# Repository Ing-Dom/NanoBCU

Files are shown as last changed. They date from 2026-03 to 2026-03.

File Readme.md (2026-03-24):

## Beschreibung

Die NanoBCU ist eine sehr kleine BCU (Bus Coupling Unit) für den KNX-TP1 Gebäudeautomatisierungsbus.  
Sie basiert auf den OnSemi NCN51xx KNX-Tranceiver-ICs. Die Größe der NanoBCU V2 beträgt lediglich 18x17x8 mm.

Mit der BCU können per UART Telegramme auf KNX-TP1 gesendet und empfangen werden. Weiterhin stellt sie die Spannungsversorgung der Geräts über den KNX-TP1 sicher.

Die Informationen hier gelten für die NanBCU V2, für die älteren V0 und V1 Versionen siehe [NanoBCU-V1](https://github.com/OpenKNX/OpenKNX/wiki/NanoBCU-V1)

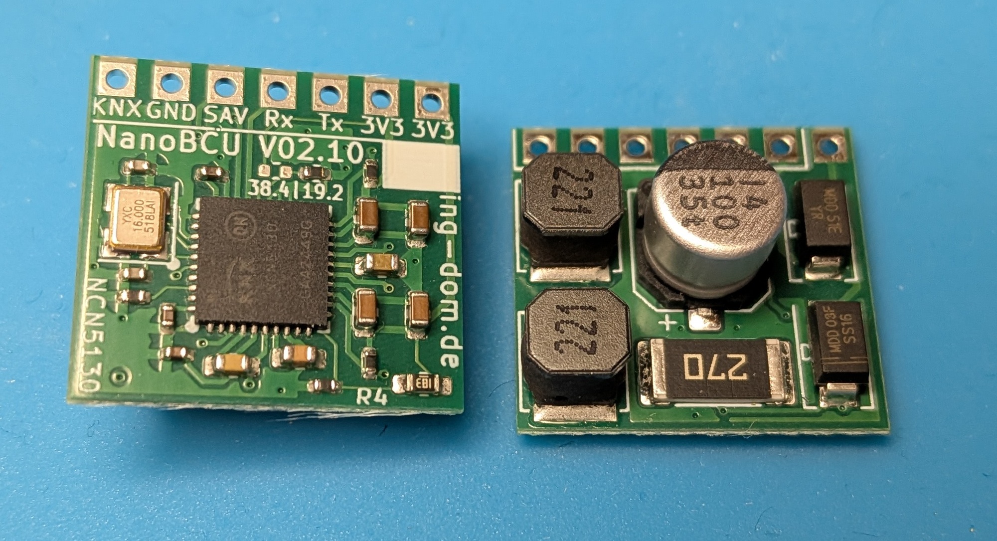
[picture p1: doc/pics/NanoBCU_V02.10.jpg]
NanoBCU V02.00 Top


## Eigenschaften

- IC: NCN5130 (auch NCN5121 und NCN5120)
- Größe: 18 x 17 x 8 mm
- Gewicht: ca. 4g
- Spannung 1: 3.3V
- Spannung 2: 3.3V, 5V, 12V, 21V. Lann durch Tausch der Widerstands R4 geändert werden beliebig geändert werden: 1.2V - 21V
- Ripple: ca. 50-100mV (Abhängig von Spannung und Strom)
- Max. Strom: 100mA @ 3.3V + 100mA @ 5V (2x 100mA nur mit NCN5130)
- Max. Busstrom: 40mA/20mA (5130/ 512x)
- UART: 19200bps 8E1 / Pegel **3.3V**, ab V02.10 wahlweise 38400bps wählbar

## Verfügbarkeit

Der Schaltplan der NanoBCU ist unter der freien [CC-BY-NC-SA](https://creativecommons.org/licenses/by-nc-sa/4.0/legalcode.de) verfügbar.

SMD-bestückte Bausätze können [hier](https://muster.ing-dom.de) gekauft werden.

Die KiCAD-Daten sind und werden nicht veröffentlicht.

## Aufbau

Eine gerade oder gewinkelte 1x7 Stift- oder Buchsenleiste RM 2.54mm einlöten.

## Dokumentation

- [Schematic V02.10](doc/NanoBCU_V02.10.sch.pdf)
- [3D-Modell V02.10](doc/NanoBCU_V02.10.step)

## Software-Integration

Es existieren diverse Bibliotheken mit denen eine NanoBCU genutzt werden kann.

Für ESP32 oder ARM-Mikrocontroller empfehlen wir den [OpenKNX stack](https://github.com/OpenKNX/knx).

Aber auch für kleinere 8Bit Controller als auch für .Net und Java existieren fertige Lösungen.

Das UART-Protokol der NCN51xx ist weitgehend kompatibel zum TPUart daher kann eine NanoBCU in gewissen Grenzen als Ersatz für eine TPUart-basierende Lösung verwendet werden.

## Hardware-Integration

Die [OpenKNX-KiCad-Lib](https://github.com/OpenKNX/OpenKNX-KiCad-Lib) enthält Footprints für diverse Montagemöglickeiten der NanoBCU.

## Benutzung des SAVE Ausgangs

Details zum Verhalten des SAVE-Pins und das Verhalten des NCN bei Busspannungsausfall stehen im jeweiligen NCN51xx-Datenblatt.

Der SAVE pin wird dazu verwendet um einen Busspannungsausfall einige Millisekunden vor dem Zusammenbrechen der 3.3V Versorgung zu erkennenen - der Kondensator der BCU puffert genug Energie um ggf. Daten zu persistieren.

Typischerweise beträgt die Zeit zwischen 50 und 200ms, abhängig vom Strombedarf des Gerätes.

Hier sieht man eine Messung mit einem Gerät mit 8.5ma Stromaufnahme aus dem Bus (ca 35mA @3.3V).
Wie man sehen kann, bleiben ca. 150ms bis die 3.3V Spannung einbricht.
Achtung, der SAVE pin kann prellen!

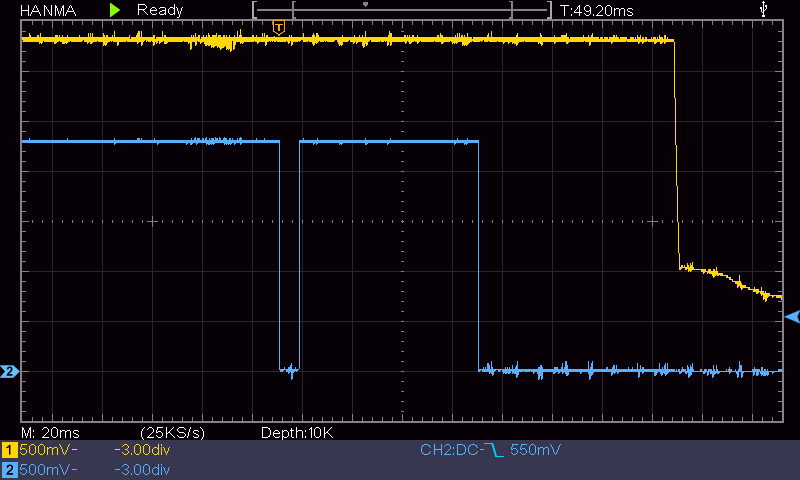
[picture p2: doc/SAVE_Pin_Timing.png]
SAVE Pin Timing


gelb: 3.3V Ausgang der BCU, blau: SAVE pin

## Versionsgeschichte

- V00.10 - erste Prototypenserie
- V00.11 - neuer C4 Kondensator Footprint für die optionale Benutzung eines flachen Tantalkondensators, PCB-Dicke auf 1.0mm reduziert
- V01.00 - OpenKNX-Logo
- V01.10 - Optimierung auf doppelseitige SMD-Maschinenbestückung (C4 nur Alu Cap)
- V02.00 - Verkleinerung auf 17x18, quadratische Lötpads, NCN5130 als Standard-NCN, PCB-Dicke auf 0.8mm reduziert
- V02.10 - Baudrate 19.2/38.4k einstellbar

## Varianten

Details zu den möglichen Bestückvarianten sind im Schaltplan zu finden.

## Links

- [Vorstellungs- / Entwicklunsthread im KNX User Forum](https://knx-user-forum.de/forum/projektforen/konnekting/1603350-nanobcu-ncn5120-weiterentwicklung-der-microbcu2)
- [Sammelbestellung KNX User Forum](https://knx-user-forum.de/forum/projektforen/openknx/1748827-sammelbestellung-nanobcu-und-zubeh%C3%B6r)

## Bilder

NanoBCU V02.00 Top

NanoBCU V02.00 Top

NanoBCU V02.00 Bottom

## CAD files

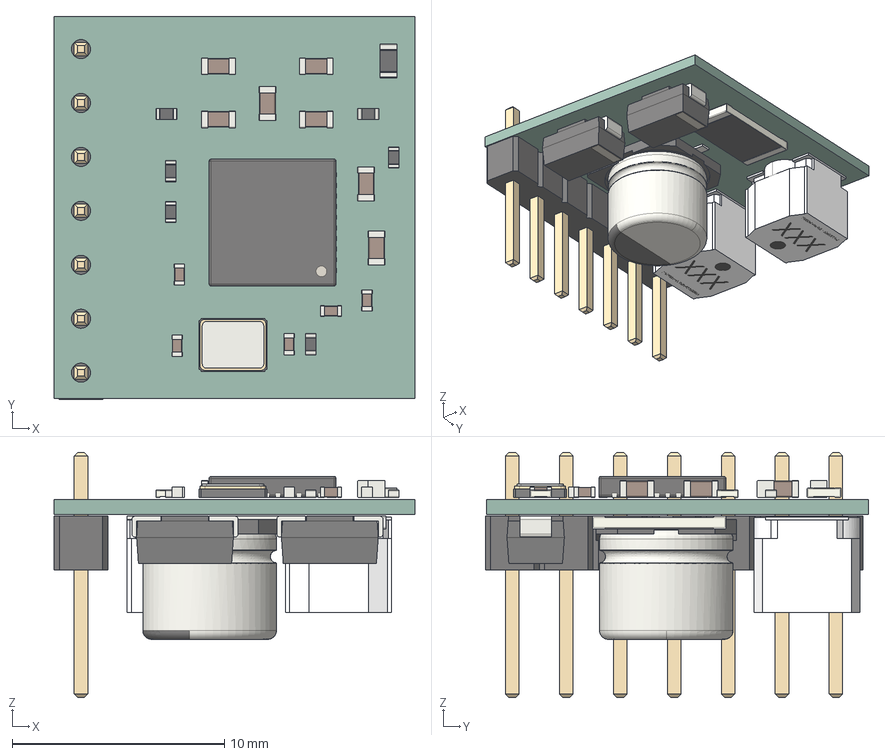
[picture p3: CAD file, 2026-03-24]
doc/NanoBCU_V02.10.step
17.0 x 18.0 x 11.5 mm
C_0603_1608Metric x 7
C_0402_1005Metric x 5
Crystal_SMD_3225-4Pin_3.2x2.5mm
R_0402_1005Metric x 6
QFN-40-1EP_6x6mm_P0.5mm_EP4.6x4.6mm
R_0603_1608Metric
CP_Elec_6.3x5.8
PinHeader_1x07_P2.54mm_Vertical
D_SMA x 2
VLS5045EX_C(3Dmodel) x 2
VLS5045EX_T(3Dmodel) x 2
R_2512_6332Metric
NanoBCU_PCB

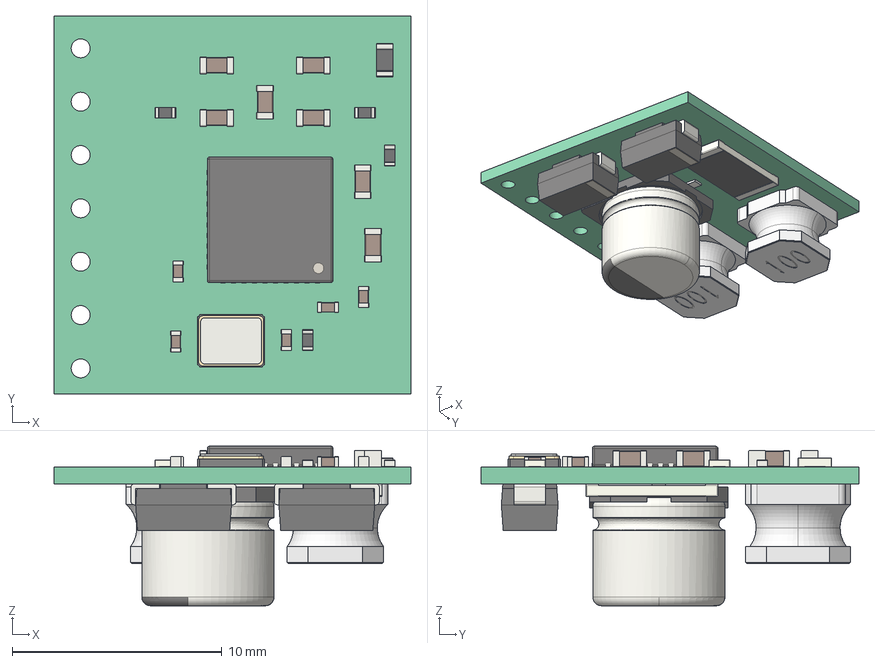
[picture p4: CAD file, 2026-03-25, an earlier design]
doc/NanoBCU_V02.00.step
17.0 x 18.0 x 7.60 mm
Local_CS_8f96
Pcb_8f96
PCB_Sketch_8f96
C101_C_0603_1608Metric_5FFA3646
R6_R_0402_1005Metric_6423BDE2
R5_R_0402_1005Metric_5F7CC408
C111_C_0603_1608Metric_5FFA3657
C3_C_0402_1005Metric_5FFB0728
C2_C_0603_1608Metric_5F7CC168
R4_R_0603_1608Metric_5FFA04AE
C6_C_0402_1005Metric_5F7F7249
C5_C_0402_1005Metric_5F7CC1F8
C41_C_0603_1608Metric_5FACF283
R3_R_0402_1005Metric_5F7CC3D8
R2_R_0402_1005Metric_64272D06
C9_C_0402_1005Metric_5FFA6139
C8_C_0402_1005Metric_5FFA6163
C10_C_0603_1608Metric_5F7CC1C8
C11_C_0603_1608Metric_5F7E1A3A
X1_Crystal_SMD_3225-4Pin_3.2x2.5mm_5F7CC372
U1_QFN-40-1EP_6x6mm_Pitch0.5mm_5F7D92D4
C1_C_0603_1608Metric_5FFB093B
L1_9999-5040-10uH_5FAB9F93
L2_9999-5040-10uH_5F7CB1DF
R1_R_2512_6332Metric_607A325D
D2_D_SMA_5F798DFE
D1_D_SMA_6423C965
C4_CP_Elec_63x58_5DADC971

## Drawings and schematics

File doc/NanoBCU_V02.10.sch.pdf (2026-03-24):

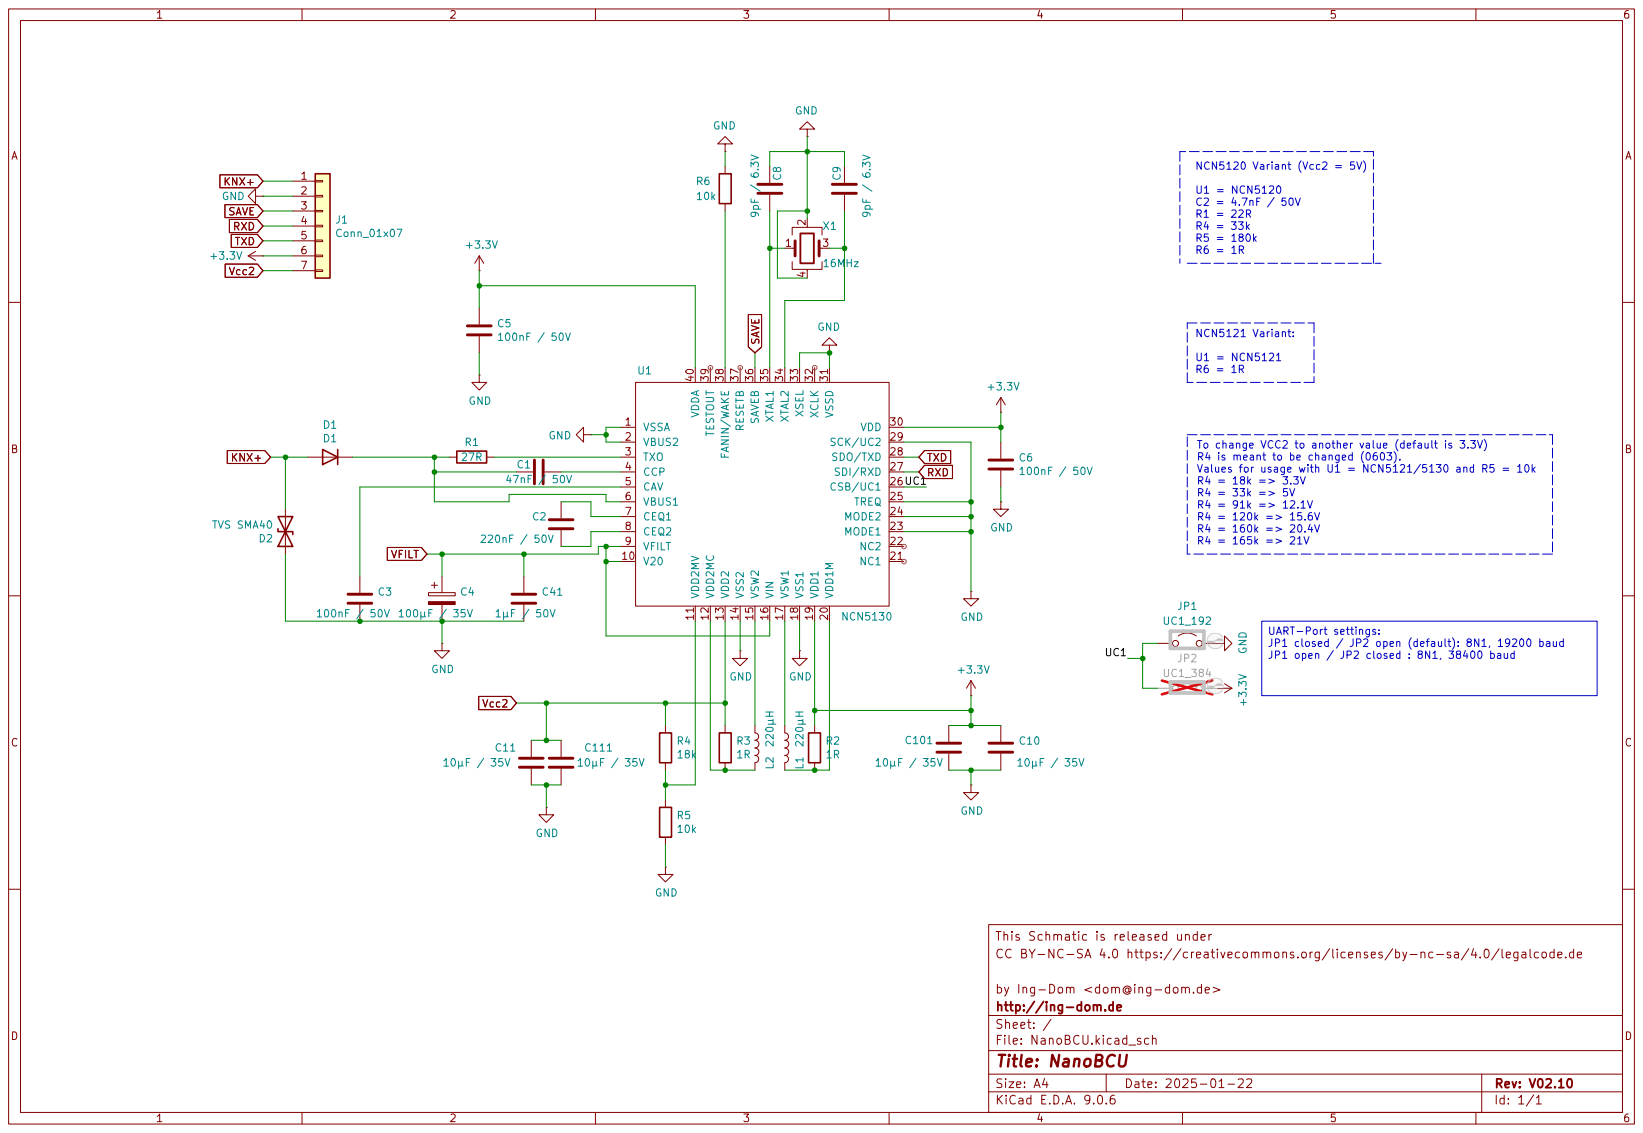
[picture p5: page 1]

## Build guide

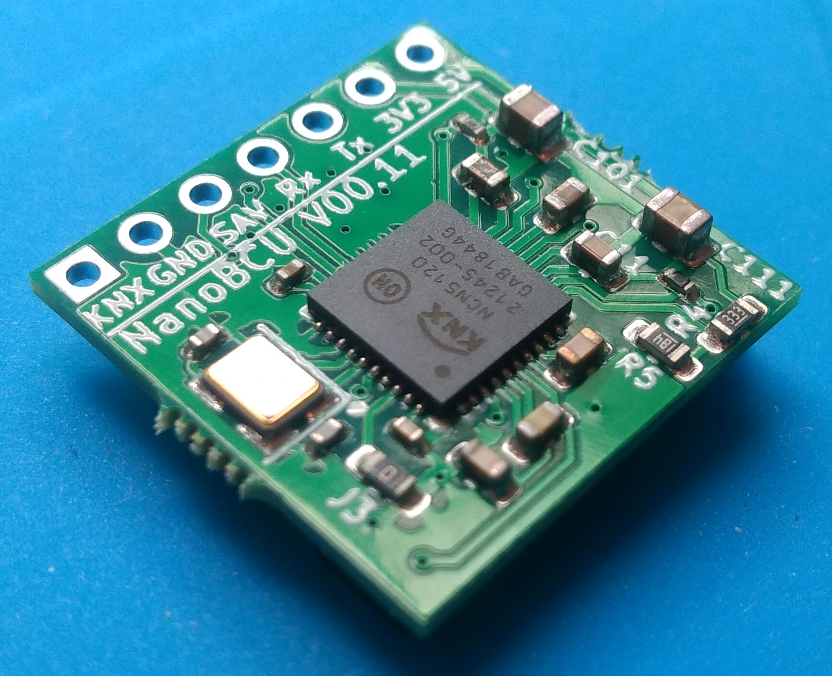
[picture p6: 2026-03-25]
doc/pics/NanoBCU_V00_11_soldered_top.jpg

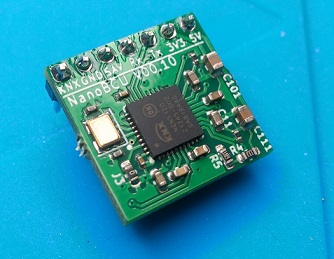
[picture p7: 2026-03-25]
doc/pics/NanoBCU_V00_10_soldered_top - Small.jpg

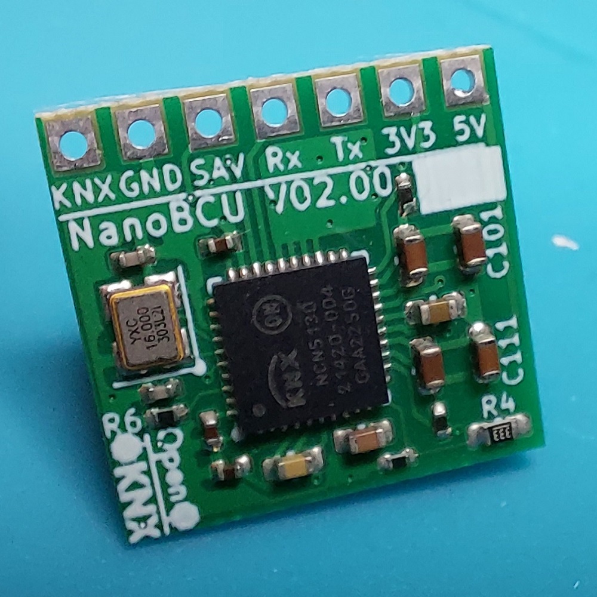
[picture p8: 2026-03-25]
doc/pics/NanoBCU_V02.00_soldered_Top.jpg

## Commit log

2026-03-24 add NanoBCU v02,10 documentation
    [NanoBCU_V02.10.step]
2026-03-25 add old docu
    [NanoBCU_V02.00.step]
